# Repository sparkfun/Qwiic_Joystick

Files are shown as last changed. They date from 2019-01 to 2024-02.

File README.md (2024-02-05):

SparkFun Qwiic Joystick
========================================

SparkFun Qwiic Joystick

[*SparkFun Qwiic Joystick (COM-15168)*](https://www.sparkfun.com/products/15168)

Now, you can easily add an HID/controller to your project! The [SparkFun Qwiic Joystick](https://www.sparkfun.com/products/15168) combines the convenience of the Qwiic connection system and an analog joystick that feels reminiscent of the _thumbstick_ from a PlayStation 2 controller.

Thanks to an ATtiny85 on the [Qwiic Joystick](https://www.sparkfun.com/products/15168), all the necessary bits are taken care of and your microcontroller only needs to look for your inputs in the registers of the I<sup>2</sup>C device.

<h3 style="text-decoration: underline;">Factory Default I2C Slave Address: 0x20</h3>

<h3 style="text-decoration: underline;">I2C Registers</h3><br/>

| Address | Contents |
| --- | --- |
| 0x00 | Default I2C Address |
| 0x01-0x02 | Firmware Version |
| 0x03-0x04 | Horizontal Position (MSB First) |
| 0x05-0x06 | Vertical Position (MSB First) |
| 0x07 | Button Position; clears after read. |
| 0x08 | Button Status: Indicates if button was pressed since last read of button state (i.e. last time reg `0x07` was read). |
| 0x09 | Lock Register for I2C Address Change |
| 0x0A | Current I2C Slave Address. Can only be changed once Lock Register is set to 0x13, then it clears the Lock Register. |

In the registers for the joystick position, the MSB contains the first 8 bits of the 10-bit ADC value and the LSB contains the last two bits. As an example, this is how the library converts the two registers back to a 10-bit value.

`uint_16t full10bitvalue = (MSB | LSB)>>6;`

You could potentially only look at the MSB and get an 8-bit (256 position) reading. The firmware was intentionally written this way in the hopes that it would be useful for customers who don't need the full resolution of the joystick position.

Repository Contents
-------------------

* **/Firmware** - Firmware for ATtiny85 and Python Example Code 
* **/Hardware** - Eagle design files (.brd, .sch)

Documentation
--------------
* **[Library](https://github.com/sparkfun/SparkFun_Qwiic_Joystick_Arduino_Library)** - Arduino library for the Qwiic Joystick.
* **[Hookup Guide](https://learn.sparkfun.com/tutorials/qwiic-joystick-hookup-guide)** - Basic hookup guide for the Qwiic Joystick.

Product Versions
----------------
* [COM-15168](https://www.sparkfun.com/products/15168)- Retail packaging of standard description here

Version History
---------------
* [SparkFun Qwiic Joystick COM-15168](https://www.sparkfun.com/products/15168) - Firmware was update so that the board acts like a *normal* I2C slave device, the silk screen was changed to follow retail product guidelines, and the ISP pins were reconfigured for programming on a test bed.
* [SparkX Qwiic Joystiic v1.1 SPX-14656](https://www.sparkfun.com/products/14656) - Version 1.1 is a minor revision which adds a power LED and corrects the wide IC footprint. It's functionally identical to the previous version.
* [SparkX Qwiic Joystiic SPX-14619](https://www.sparkfun.com/products/retired/14619) - Original SparkX Joystiic.

License Information
-------------------

This product is _**open source**_! 

Please review the LICENSE.md file for license information. 

If you have any questions or concerns on licensing, please visit the [SparkFun Forum](https://forum.sparkfun.com/index.php) and post a topic. For more general questions related to our qwiic system, please visit this section of the forum: [SparkFun Forums: QWIIC SYSTEMS](https://forum.sparkfun.com/viewforum.php?f=105)

Distributed as-is; no warranty is given.

- Your friends at SparkFun.

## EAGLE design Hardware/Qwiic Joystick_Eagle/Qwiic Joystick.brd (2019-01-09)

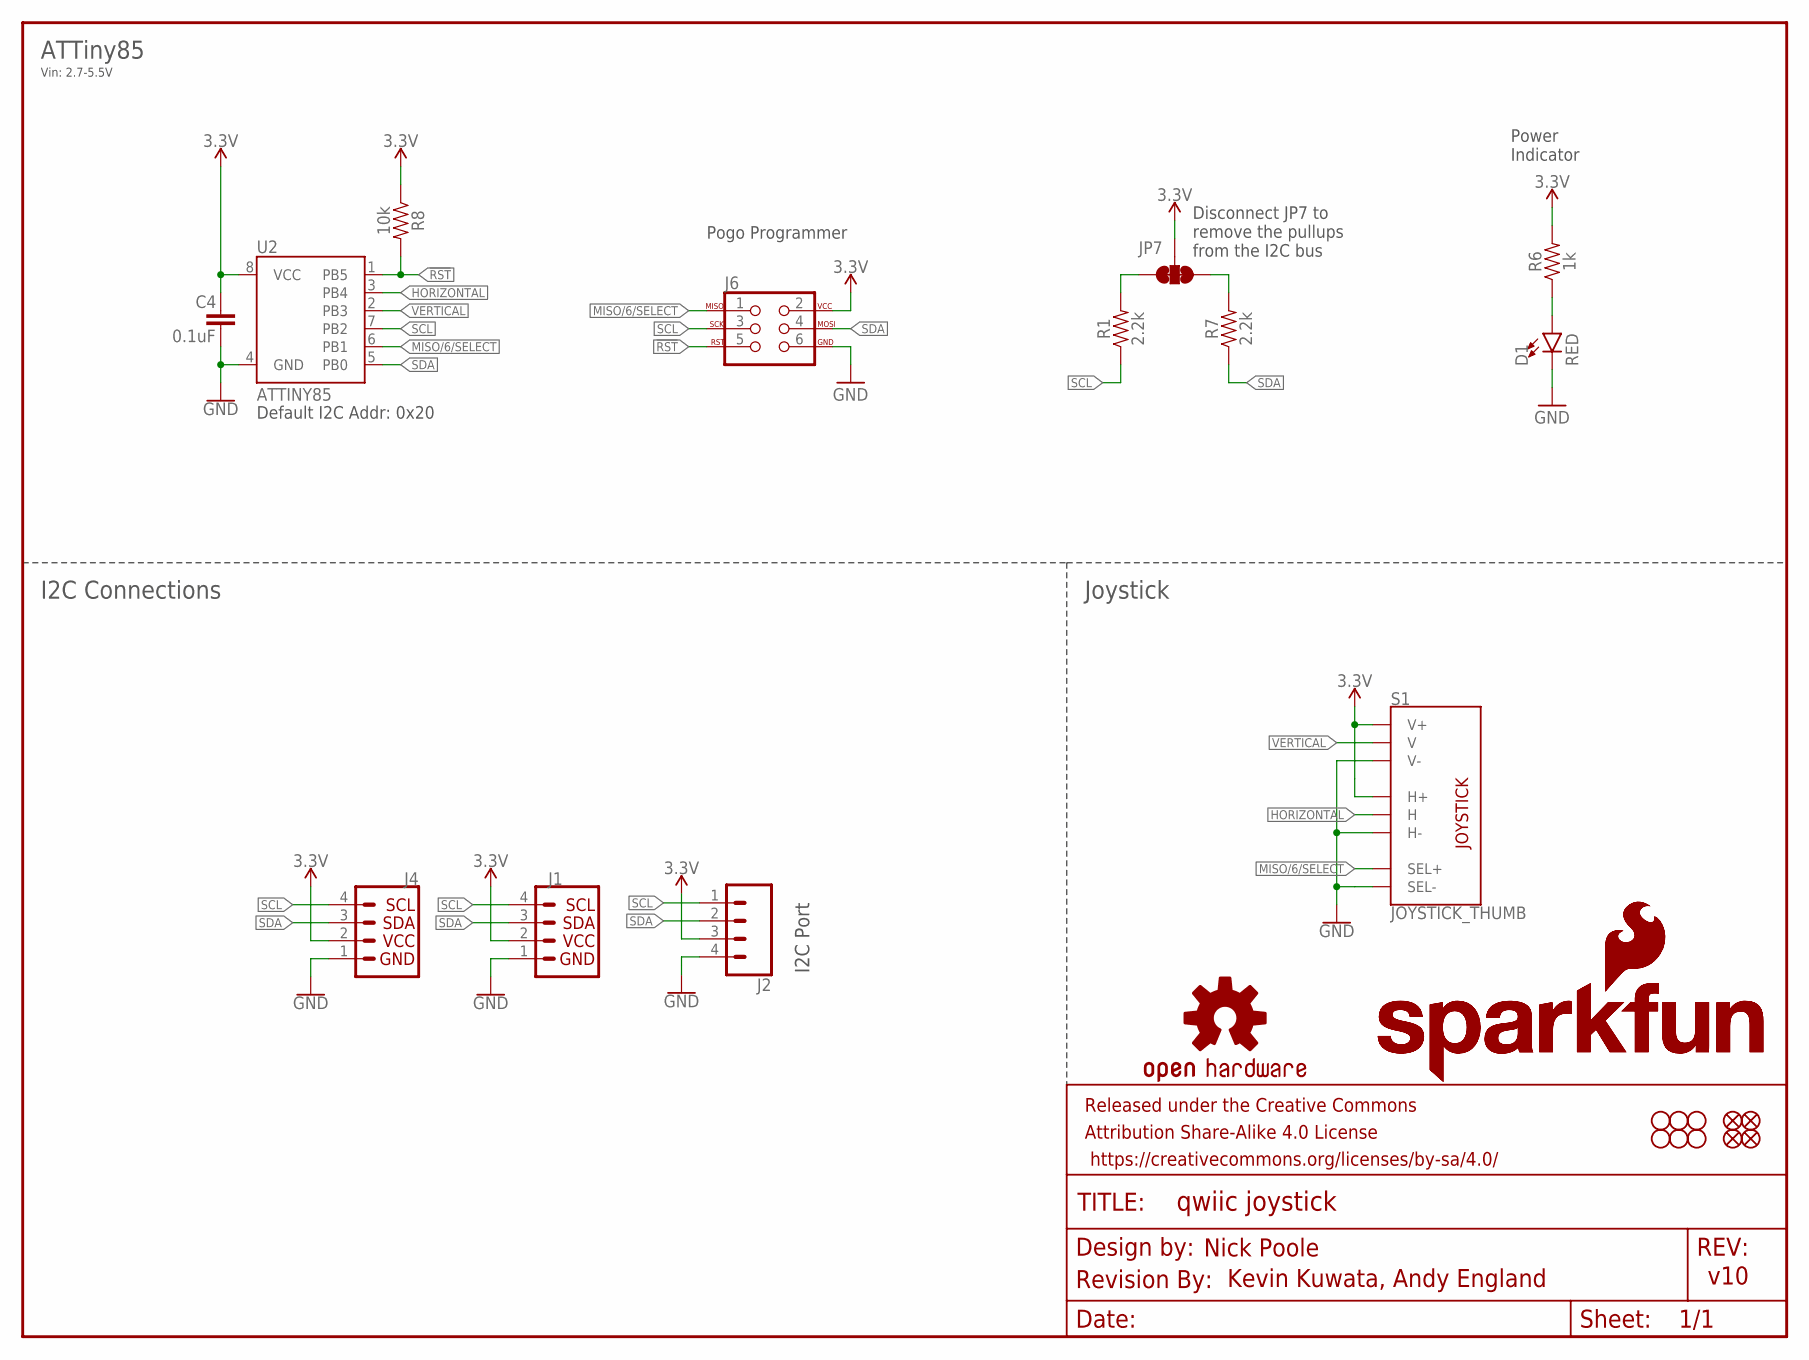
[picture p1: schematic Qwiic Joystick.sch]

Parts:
C4: 0.1uF; 0603
D1: RED; LED-0603
FRAME1: FRAME-LETTER; CREATIVE_COMMONS
H1, H2, H3, H4, H5, H6: STAND-OFF
J1, J4: QWIIC_CONNECTORJS-1MM; 1X04_1MM_RA
J2: CONN_041X04_NO_SILK; 1X04_NO_SILK
J6: AVR_SPI_PROG_3X2TESTPOINTS; 2X3_TEST_POINTS
JP1, JP2, JP3, JP6: FIDUCIALUFIDUCIAL; MICRO-FIDUCIAL
JP7: JUMPER-SMT_3_2-NC_TRACE_NO-SILK; SMT-JUMPER_3_2-NC_TRACE_NO-SILK
LOGO1: OSHW-LOGOMINI; OSHW-LOGO-MINI
LOGO2: REVISION
R1, R7: 2.2k; 0603
R6: 1k; 0603
R8: 10k; 0603
S1: JOYSTICK_THUMB; JOYSTICK
U2: ATTINY85
U$1, U$2: SFE_LOGO_NAME_FLAME.1_INCH; SFE_LOGO_NAME_FLAME_.1

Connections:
3.3V: C4.1, J1.2, J2.3, J4.2, J6.2, JP7.2, R6.2, R8.1, S1.H1 (H+), S1.V1 (V+), U2.8 (VCC)
!RST: J6.5, R8.2, U2.1 (PB5)
GND: C4.2, D1.C, J1.1, J2.4, J4.1, J6.6, S1.B2A (SEL-), S1.H3 (H-), S1.V3 (V-), U2.4 (GND)
HORIZONTAL: S1.H2 (H), U2.3 (PB4)
MISO/6/SELECT: J6.1, S1.B1A (SEL+), U2.6 (PB1)
unnamed: D1.A, R6.1
unnamed: JP7.1, R7.2
unnamed: JP7.3, R1.2
SCL: J1.4, J2.1, J4.4, J6.3, R1.1, U2.7 (PB2)
SDA: J1.3, J2.2, J4.3, J6.4, R7.1, U2.5 (PB0)
VERTICAL: S1.V2 (V), U2.2 (PB3)

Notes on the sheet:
Nick Poole
v10
Power Indicator
Kevin Kuwata, Andy England
I2C Port
Pogo Programmer
Default I2C Addr: 0x20
Disconnect JP7 to remove the pullups from the I2C bus
ATTiny85
Joystick
I2C Connections
Vin: 2.7-5.5V

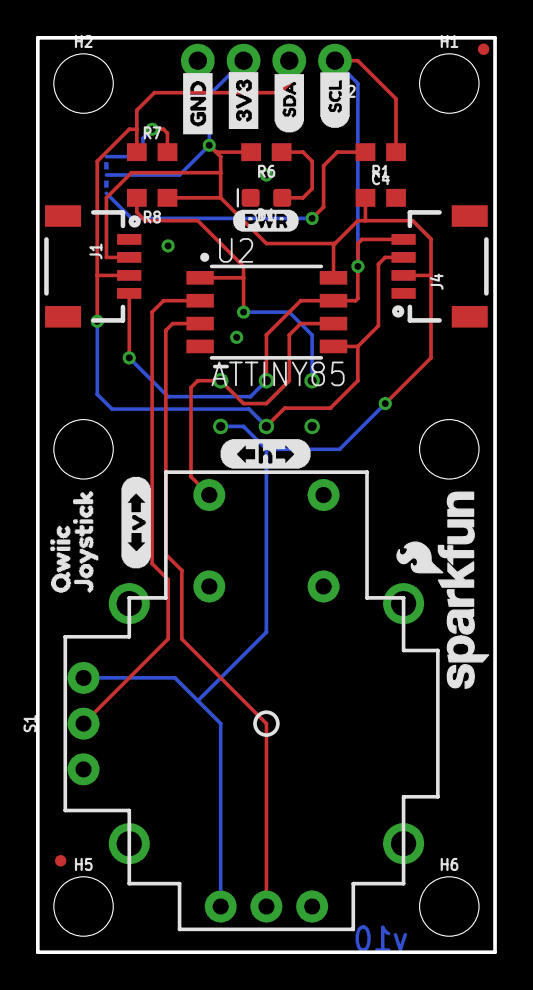
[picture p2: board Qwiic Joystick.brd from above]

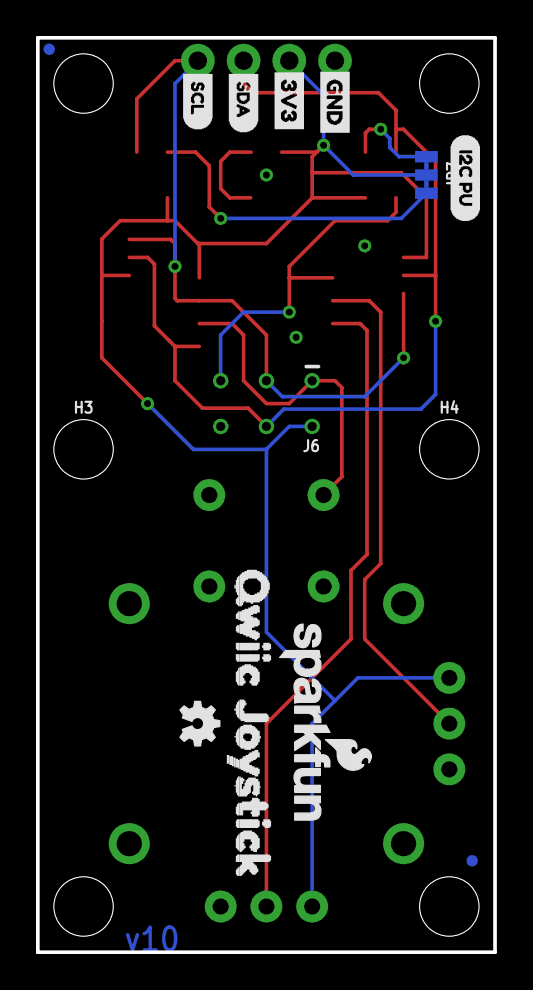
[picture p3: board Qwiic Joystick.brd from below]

Board: 2 copper layers, 25.4 x 50.8 mm, 43 parts (14 on the bottom side), 11 nets.

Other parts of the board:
U$3: QWIIC0
U$4: I2C_PU0
U$5: SDA0
U$6, U$8: GND4
U$7: ##V##1
U$9: SCL1
U$10: JOYSTICK0
U$11: SCL3
U$12: SDA2
U$13: QWIIC_JOYSTICK1
U$14: PWR-()-03
U$15: ##H##0
U$16, U$17: 3V35

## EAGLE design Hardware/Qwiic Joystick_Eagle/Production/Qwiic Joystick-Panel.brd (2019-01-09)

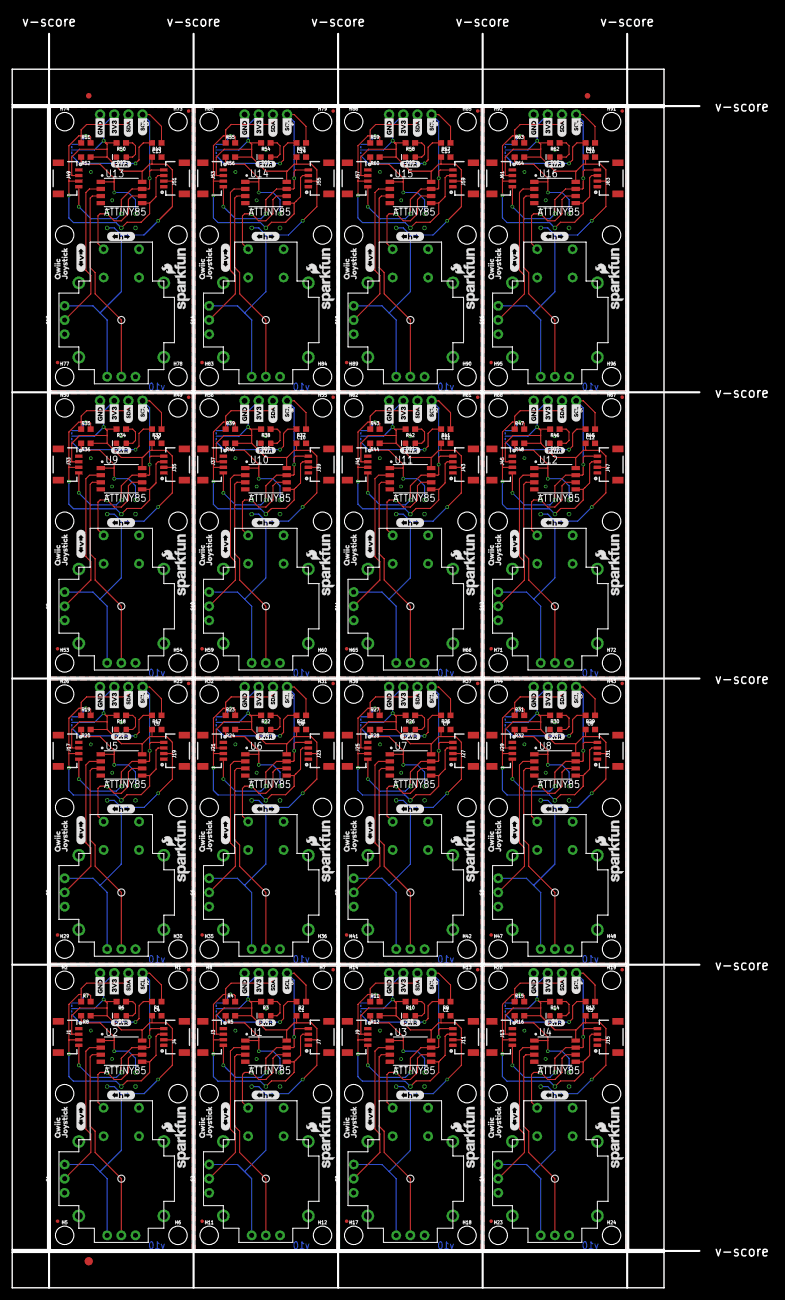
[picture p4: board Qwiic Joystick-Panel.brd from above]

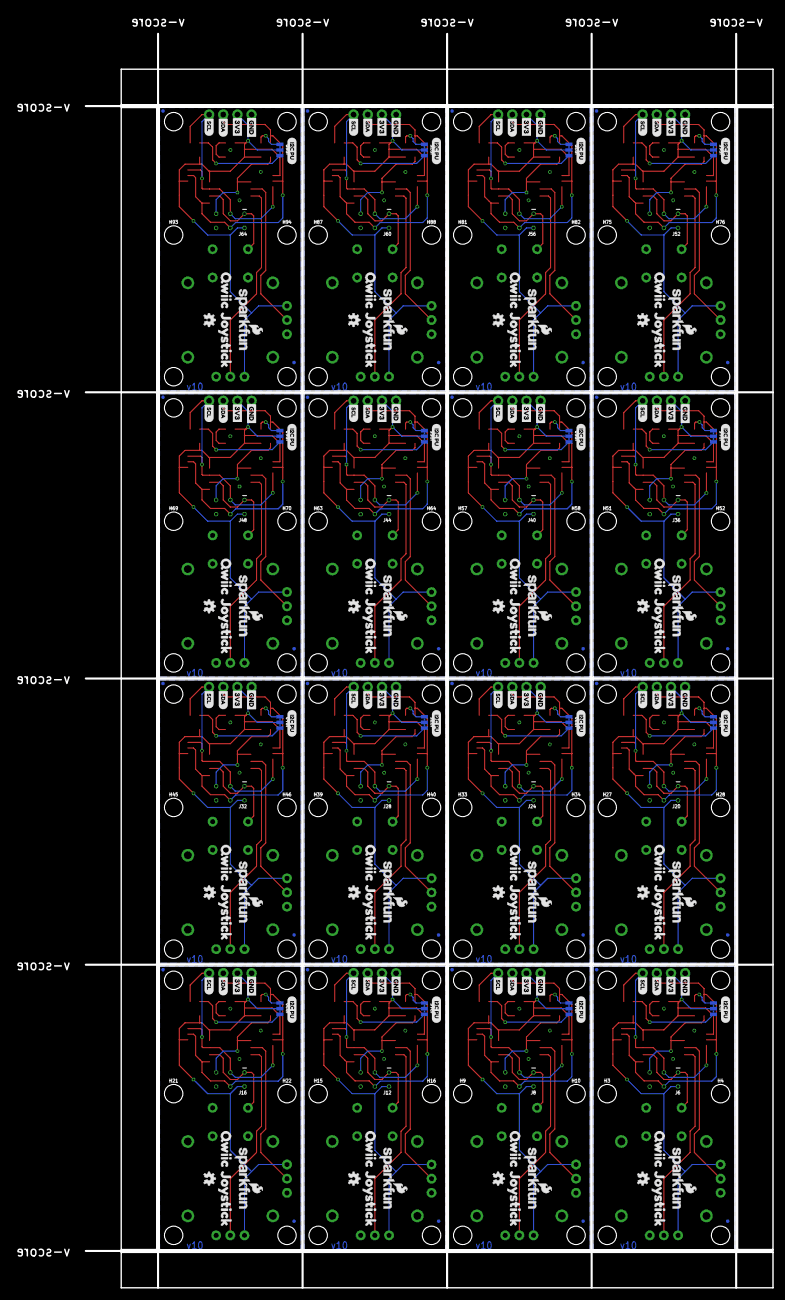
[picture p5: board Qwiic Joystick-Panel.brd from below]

Board: 2 copper layers, 123.2 x 224.8 mm, 675 parts (224 on the bottom side), 176 nets.

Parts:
C1, C2, C3, C4, C5, C6, C7, C8, C9, C10, C11, C12, C13, C14, C15, C16: 0.1uF; 0603
D1, D2, D3, D4, D5, D6, D7, D8, D9, D10, D11, D12, D13, D14, D15, D16: RED; LED-0603
E$1, E$2: FIDUCIAL-1X2
E$3: FIDUCIAL-1.5X3
H1, H2, H3, H4, H5, H6, H7, H8, H9, H10, H11, H12, H13, H14, H15, H16, H17, H18, H19, H20, H21, H22, H23, H24, H25, H26, H27, H28, H29, H30, H31, H32, H33, H34, H35, H36, H37, H38, H39, H40, H41, H42, H43, H44, H45, H46, H47, H48, H49, H50, H51, H52, H53, H54, H55, H56, H57, H58, H59, H60, H61, H62, H63, H64, H65, H66, H67, H68, H69, H70, H71, H72, H73, H74, H75, H76, H77, H78, H79, H80, H81, H82, H83, H84, H85, H86, H87, H88, H89, H90, H91, H92, H93, H94, H95, H96: STAND-OFF
J1, J3, J4, J7, J9, J11, J13, J15, J17, J19, J21, J23, J25, J27, J29, J31, J33, J35, J37, J39, J41, J43, J45, J47, J49, J51, J53, J55, J57, J59, J61, J63: 1X04_1MM_RA
J2, J5, J10, J14, J18, J22, J26, J30, J34, J38, J42, J46, J50, J54, J58, J62: 1X04_NO_SILK
J6, J8, J12, J16, J20, J24, J28, J32, J36, J40, J44, J48, J52, J56, J60, J64: AVR_SPI_PROG_3X2TESTPOINTS; 2X3_TEST_POINTS
JP1, JP2, JP3, JP4, JP5, JP6, JP8, JP9, JP11, JP12, JP13, JP14, JP16, JP17, JP18, JP19, JP21, JP22, JP23, JP24, JP26, JP27, JP28, JP29, JP31, JP32, JP33, JP34, JP36, JP37, JP38, JP39, JP41, JP42, JP43, JP44, JP46, JP47, JP48, JP49, JP51, JP52, JP53, JP54, JP56, JP57, JP58, JP59, JP61, JP62, JP63, JP64, JP66, JP67, JP68, JP69, JP71, JP72, JP73, JP74, JP76, JP77, JP78, JP79: FIDUCIALUFIDUCIAL; MICRO-FIDUCIAL
JP7, JP10, JP15, JP20, JP25, JP30, JP35, JP40, JP45, JP50, JP55, JP60, JP65, JP70, JP75, JP80: JUMPER-SMT_3_2-NC_TRACE_NO-SILK; SMT-JUMPER_3_2-NC_TRACE_NO-SILK
LOGO1, LOGO3, LOGO5, LOGO7, LOGO9, LOGO11, LOGO13, LOGO15, LOGO17, LOGO19, LOGO21, LOGO23, LOGO25, LOGO27, LOGO29, LOGO31: OSHW-LOGOMINI; OSHW-LOGO-MINI
LOGO2, LOGO4, LOGO6, LOGO8, LOGO10, LOGO12, LOGO14, LOGO16, LOGO18, LOGO20, LOGO22, LOGO24, LOGO26, LOGO28, LOGO30, LOGO32: REVISION
R1, R2, R4, R7, R9, R11, R13, R15, R17, R19, R21, R23, R25, R27, R29, R31, R33, R35, R37, R39, R41, R43, R45, R47, R49, R51, R53, R55, R57, R59, R61, R63: 2.2k; 0603
R3, R6, R10, R14, R18, R22, R26, R30, R34, R38, R42, R46, R50, R54, R58, R62: 1k; 0603
R5, R8, R12, R16, R20, R24, R28, R32, R36, R40, R44, R48, R52, R56, R60, R64: 10k; 0603
S1, S2, S3, S4, S5, S6, S7, S8, S9, S10, S11, S12, S13, S14, S15, S16: JOYSTICK_THUMB; JOYSTICK
U1, U2, U3, U4, U5, U6, U7, U8, U9, U10, U11, U12, U13, U14, U15, U16: ATTINY85
U$1, U$2, U$18, U$19, U$35, U$36, U$52, U$53, U$69, U$70, U$86, U$87, U$103, U$104, U$120, U$121, U$137, U$138, U$154, U$155, U$171, U$172, U$188, U$189, U$205, U$206, U$222, U$223, U$239, U$240, U$256, U$257: SFE_LOGO_NAME_FLAME.1_INCH; SFE_LOGO_NAME_FLAME_.1
U$3, U$33, U$50, U$67, U$84, U$101, U$118, U$135, U$152, U$169, U$186, U$203, U$220, U$237, U$254, U$271: QWIIC0
U$4, U$31, U$48, U$65, U$82, U$99, U$116, U$133, U$150, U$167, U$184, U$201, U$218, U$235, U$252, U$269: I2C_PU0
U$5, U$23, U$40, U$57, U$74, U$91, U$108, U$125, U$142, U$159, U$176, U$193, U$210, U$227, U$244, U$261: SDA0
U$6, U$8, U$27, U$28, U$44, U$45, U$61, U$62, U$78, U$79, U$95, U$96, U$112, U$113, U$129, U$130, U$146, U$147, U$163, U$164, U$180, U$181, U$197, U$198, U$214, U$215, U$231, U$232, U$248, U$249, U$265, U$266: GND4
U$7, U$21, U$38, U$55, U$72, U$89, U$106, U$123, U$140, U$157, U$174, U$191, U$208, U$225, U$242, U$259: ##V##1
U$9, U$24, U$41, U$58, U$75, U$92, U$109, U$126, U$143, U$160, U$177, U$194, U$211, U$228, U$245, U$262: SCL1
U$10, U$34, U$51, U$68, U$85, U$102, U$119, U$136, U$153, U$170, U$187, U$204, U$221, U$238, U$255, U$272: JOYSTICK0
U$11, U$25, U$42, U$59, U$76, U$93, U$110, U$127, U$144, U$161, U$178, U$195, U$212, U$229, U$246, U$263: SCL3
U$12, U$26, U$43, U$60, U$77, U$94, U$111, U$128, U$145, U$162, U$179, U$196, U$213, U$230, U$247, U$264: SDA2
U$13, U$32, U$49, U$66, U$83, U$100, U$117, U$134, U$151, U$168, U$185, U$202, U$219, U$236, U$253, U$270: QWIIC_JOYSTICK1
U$14, U$20, U$37, U$54, U$71, U$88, U$105, U$122, U$139, U$156, U$173, U$190, U$207, U$224, U$241, U$258: PWR-()-03
U$15, U$22, U$39, U$56, U$73, U$90, U$107, U$124, U$141, U$158, U$175, U$192, U$209, U$226, U$243, U$260: ##H##0
U$16, U$17, U$29, U$30, U$46, U$47, U$63, U$64, U$80, U$81, U$97, U$98, U$114, U$115, U$131, U$132, U$148, U$149, U$165, U$166, U$182, U$183, U$199, U$200, U$216, U$217, U$233, U$234, U$250, U$251, U$267, U$268: 3V35

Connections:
3.3V: C4.1, J1.2, J2.3, J4.2, J6.2, JP7.2, R6.2, R8.1, S1.H1, S1.V1, U2.8
3.3V1: C1.1, J3.2, J5.3, J7.2, J8.2, JP10.2, R3.2, R5.1, S2.H1, S2.V1, U1.8
3.3V2: C2.1, J9.2, J10.3, J11.2, J12.2, JP15.2, R10.2, R12.1, S3.H1, S3.V1, U3.8
3.3V3: C3.1, J13.2, J14.3, J15.2, J16.2, JP20.2, R14.2, R16.1, S4.H1, S4.V1, U4.8
3.3V4: C5.1, J17.2, J18.3, J19.2, J20.2, JP25.2, R18.2, R20.1, S5.H1, S5.V1, U5.8
3.3V5: C6.1, J21.2, J22.3, J23.2, J24.2, JP30.2, R22.2, R24.1, S6.H1, S6.V1, U6.8
3.3V6: C7.1, J25.2, J26.3, J27.2, J28.2, JP35.2, R26.2, R28.1, S7.H1, S7.V1, U7.8
3.3V7: C8.1, J29.2, J30.3, J31.2, J32.2, JP40.2, R30.2, R32.1, S8.H1, S8.V1, U8.8
3.3V8: C9.1, J33.2, J34.3, J35.2, J36.2, JP45.2, R34.2, R36.1, S9.H1, S9.V1, U9.8
3.3V9: C10.1, J37.2, J38.3, J39.2, J40.2, JP50.2, R38.2, R40.1, S10.H1, S10.V1, U10.8
3.3V10: C11.1, J41.2, J42.3, J43.2, J44.2, JP55.2, R42.2, R44.1, S11.H1, S11.V1, U11.8
3.3V11: C12.1, J45.2, J46.3, J47.2, J48.2, JP60.2, R46.2, R48.1, S12.H1, S12.V1, U12.8
3.3V12: C13.1, J49.2, J50.3, J51.2, J52.2, JP65.2, R50.2, R52.1, S13.H1, S13.V1, U13.8
3.3V13: C14.1, J53.2, J54.3, J55.2, J56.2, JP70.2, R54.2, R56.1, S14.H1, S14.V1, U14.8
3.3V14: C15.1, J57.2, J58.3, J59.2, J60.2, JP75.2, R58.2, R60.1, S15.H1, S15.V1, U15.8
3.3V15: C16.1, J61.2, J62.3, J63.2, J64.2, JP80.2, R62.2, R64.1, S16.H1, S16.V1, U16.8
!RST: J6.5, R8.2, U2.1
!RST1: J8.5, R5.2, U1.1
!RST2: J12.5, R12.2, U3.1
!RST3: J16.5, R16.2, U4.1
!RST4: J20.5, R20.2, U5.1
!RST5: J24.5, R24.2, U6.1
!RST6: J28.5, R28.2, U7.1
!RST7: J32.5, R32.2, U8.1
!RST8: J36.5, R36.2, U9.1
!RST9: J40.5, R40.2, U10.1
!RST10: J44.5, R44.2, U11.1
!RST11: J48.5, R48.2, U12.1
!RST12: J52.5, R52.2, U13.1
!RST13: J56.5, R56.2, U14.1
!RST14: J60.5, R60.2, U15.1
!RST15: J64.5, R64.2, U16.1
GND: C4.2, D1.C, J1.1, J2.4, J4.1, J6.6, S1.B2A, S1.H3, S1.V3, U2.4
GND1: C1.2, D2.C, J3.1, J5.4, J7.1, J8.6, S2.B2A, S2.H3, S2.V3, U1.4
GND2: C2.2, D3.C, J9.1, J10.4, J11.1, J12.6, S3.B2A, S3.H3, S3.V3, U3.4
GND3: C3.2, D4.C, J13.1, J14.4, J15.1, J16.6, S4.B2A, S4.H3, S4.V3, U4.4
GND4: C5.2, D5.C, J17.1, J18.4, J19.1, J20.6, S5.B2A, S5.H3, S5.V3, U5.4
GND5: C6.2, D6.C, J21.1, J22.4, J23.1, J24.6, S6.B2A, S6.H3, S6.V3, U6.4
GND6: C7.2, D7.C, J25.1, J26.4, J27.1, J28.6, S7.B2A, S7.H3, S7.V3, U7.4
GND7: C8.2, D8.C, J29.1, J30.4, J31.1, J32.6, S8.B2A, S8.H3, S8.V3, U8.4
GND8: C9.2, D9.C, J33.1, J34.4, J35.1, J36.6, S9.B2A, S9.H3, S9.V3, U9.4
GND9: C10.2, D10.C, J37.1, J38.4, J39.1, J40.6, S10.B2A, S10.H3, S10.V3, U10.4
GND10: C11.2, D11.C, J41.1, J42.4, J43.1, J44.6, S11.B2A, S11.H3, S11.V3, U11.4
GND11: C12.2, D12.C, J45.1, J46.4, J47.1, J48.6, S12.B2A, S12.H3, S12.V3, U12.4
GND12: C13.2, D13.C, J49.1, J50.4, J51.1, J52.6, S13.B2A, S13.H3, S13.V3, U13.4
GND13: C14.2, D14.C, J53.1, J54.4, J55.1, J56.6, S14.B2A, S14.H3, S14.V3, U14.4
GND14: C15.2, D15.C, J57.1, J58.4, J59.1, J60.6, S15.B2A, S15.H3, S15.V3, U15.4
GND15: C16.2, D16.C, J61.1, J62.4, J63.1, J64.6, S16.B2A, S16.H3, S16.V3, U16.4
HORIZONTAL: S1.H2, U2.3
HORIZONTAL1: S2.H2, U1.3
HORIZONTAL2: S3.H2, U3.3
HORIZONTAL3: S4.H2, U4.3
HORIZONTAL4: S5.H2, U5.3
HORIZONTAL5: S6.H2, U6.3
HORIZONTAL6: S7.H2, U7.3
HORIZONTAL7: S8.H2, U8.3
HORIZONTAL8: S9.H2, U9.3
HORIZONTAL9: S10.H2, U10.3
HORIZONTAL10: S11.H2, U11.3
HORIZONTAL11: S12.H2, U12.3
HORIZONTAL12: S13.H2, U13.3
HORIZONTAL13: S14.H2, U14.3
HORIZONTAL14: S15.H2, U15.3
HORIZONTAL15: S16.H2, U16.3
MISO/6/SELECT: J6.1, S1.B1A, U2.6
MISO/6/SELECT1: J8.1, S2.B1A, U1.6
MISO/6/SELECT2: J12.1, S3.B1A, U3.6
MISO/6/SELECT3: J16.1, S4.B1A, U4.6
MISO/6/SELECT4: J20.1, S5.B1A, U5.6
MISO/6/SELECT5: J24.1, S6.B1A, U6.6
MISO/6/SELECT6: J28.1, S7.B1A, U7.6
MISO/6/SELECT7: J32.1, S8.B1A, U8.6
MISO/6/SELECT8: J36.1, S9.B1A, U9.6
MISO/6/SELECT9: J40.1, S10.B1A, U10.6
MISO/6/SELECT10: J44.1, S11.B1A, U11.6
MISO/6/SELECT11: J48.1, S12.B1A, U12.6
MISO/6/SELECT12: J52.1, S13.B1A, U13.6
MISO/6/SELECT13: J56.1, S14.B1A, U14.6
MISO/6/SELECT14: J60.1, S15.B1A, U15.6
MISO/6/SELECT15: J64.1, S16.B1A, U16.6
unnamed: D1.A, R6.1
unnamed: JP7.1, R7.2
unnamed: JP7.3, R1.2
unnamed: D2.A, R3.1
unnamed: JP10.1, R4.2
unnamed: JP10.3, R2.2
unnamed: D3.A, R10.1
unnamed: JP15.1, R11.2
unnamed: JP15.3, R9.2
unnamed: D4.A, R14.1
unnamed: JP20.1, R15.2
unnamed: JP20.3, R13.2
unnamed: D5.A, R18.1
unnamed: JP25.1, R19.2
unnamed: JP25.3, R17.2
unnamed: D6.A, R22.1
unnamed: JP30.1, R23.2
unnamed: JP30.3, R21.2
unnamed: D7.A, R26.1
unnamed: JP35.1, R27.2
unnamed: JP35.3, R25.2
unnamed: D8.A, R30.1
unnamed: JP40.1, R31.2
unnamed: JP40.3, R29.2
unnamed: D9.A, R34.1
unnamed: JP45.1, R35.2
unnamed: JP45.3, R33.2
unnamed: D10.A, R38.1
unnamed: JP50.1, R39.2
unnamed: JP50.3, R37.2
unnamed: D11.A, R42.1
unnamed: JP55.1, R43.2
unnamed: JP55.3, R41.2
unnamed: D12.A, R46.1
unnamed: JP60.1, R47.2
unnamed: JP60.3, R45.2
unnamed: D13.A, R50.1
unnamed: JP65.1, R51.2
unnamed: JP65.3, R49.2
unnamed: D14.A, R54.1
unnamed: JP70.1, R55.2
unnamed: JP70.3, R53.2
unnamed: D15.A, R58.1
unnamed: JP75.1, R59.2
unnamed: JP75.3, R57.2
unnamed: D16.A, R62.1
unnamed: JP80.1, R63.2
unnamed: JP80.3, R61.2
SCL: J1.4, J2.1, J4.4, J6.3, R1.1, U2.7
SCL1: J3.4, J5.1, J7.4, J8.3, R2.1, U1.7
SCL2: J9.4, J10.1, J11.4, J12.3, R9.1, U3.7
SCL3: J13.4, J14.1, J15.4, J16.3, R13.1, U4.7
SCL4: J17.4, J18.1, J19.4, J20.3, R17.1, U5.7
SCL5: J21.4, J22.1, J23.4, J24.3, R21.1, U6.7
SCL6: J25.4, J26.1, J27.4, J28.3, R25.1, U7.7
SCL7: J29.4, J30.1, J31.4, J32.3, R29.1, U8.7
SCL8: J33.4, J34.1, J35.4, J36.3, R33.1, U9.7
SCL9: J37.4, J38.1, J39.4, J40.3, R37.1, U10.7
SCL10: J41.4, J42.1, J43.4, J44.3, R41.1, U11.7
SCL11: J45.4, J46.1, J47.4, J48.3, R45.1, U12.7
SCL12: J49.4, J50.1, J51.4, J52.3, R49.1, U13.7
SCL13: J53.4, J54.1, J55.4, J56.3, R53.1, U14.7
SCL14: J57.4, J58.1, J59.4, J60.3, R57.1, U15.7
SCL15: J61.4, J62.1, J63.4, J64.3, R61.1, U16.7
SDA: J1.3, J2.2, J4.3, J6.4, R7.1, U2.5
SDA1: J3.3, J5.2, J7.3, J8.4, R4.1, U1.5
SDA2: J9.3, J10.2, J11.3, J12.4, R11.1, U3.5
SDA3: J13.3, J14.2, J15.3, J16.4, R15.1, U4.5
SDA4: J17.3, J18.2, J19.3, J20.4, R19.1, U5.5
SDA5: J21.3, J22.2, J23.3, J24.4, R23.1, U6.5
SDA6: J25.3, J26.2, J27.3, J28.4, R27.1, U7.5
SDA7: J29.3, J30.2, J31.3, J32.4, R31.1, U8.5
SDA8: J33.3, J34.2, J35.3, J36.4, R35.1, U9.5
SDA9: J37.3, J38.2, J39.3, J40.4, R39.1, U10.5
SDA10: J41.3, J42.2, J43.3, J44.4, R43.1, U11.5
SDA11: J45.3, J46.2, J47.3, J48.4, R47.1, U12.5
SDA12: J49.3, J50.2, J51.3, J52.4, R51.1, U13.5
SDA13: J53.3, J54.2, J55.3, J56.4, R55.1, U14.5
SDA14: J57.3, J58.2, J59.3, J60.4, R59.1, U15.5
SDA15: J61.3, J62.2, J63.3, J64.4, R63.1, U16.5
VERTICAL: S1.V2, U2.2
VERTICAL1: S2.V2, U1.2
VERTICAL2: S3.V2, U3.2
VERTICAL3: S4.V2, U4.2
VERTICAL4: S5.V2, U5.2
VERTICAL5: S6.V2, U6.2
VERTICAL6: S7.V2, U7.2
VERTICAL7: S8.V2, U8.2
VERTICAL8: S9.V2, U9.2
VERTICAL9: S10.V2, U10.2
VERTICAL10: S11.V2, U11.2
VERTICAL11: S12.V2, U12.2
VERTICAL12: S13.V2, U13.2
VERTICAL13: S14.V2, U14.2
VERTICAL14: S15.V2, U15.2
VERTICAL15: S16.V2, U16.2

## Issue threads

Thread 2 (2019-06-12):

Button Status Register 0x08 is always 1

fourstix, 2019-06-12:
Reading the button status through the Arduino library checkButton function or even directly through i2c calls to read register 0x08 always returns 1.  The register never seems to clear after being explicitly set to 0x00 through a write call in the library.  I traced the error through the Arduino library and it seems to be an issue with the firmware.

fourstix, 2019-06-12:
I am using a Qwiic Joystick with a firmware version of v2.4.

santaimpersonator, 2019-06-18:
You are correct, that is a firmware issue. I must have accidentally undone or overwrote that value in the protection map for the [Button_Status](https://github.com/sparkfun/Qwiic_Joystick/blob/master/Firmware/ATtiny85%20Firmware/Qwiic_Joystick_v24/Qwiic_Joystick_v24.ino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). There is one other thing I would like to double-check before updating the firmware again.

I'll have the tech support team reach out to you in the forum. Thanks for reaching out.

santaimpersonator, 2019-06-19:
Firmware updated. Closing issue.

Closed 2019-06-19.

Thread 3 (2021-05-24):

Button Status Register 0x08 always has 1

Oleh-Kravchenko, 2021-05-24:
Hello!
Probably is a duplicate of https://github.com/sparkfun/Qwiic_Joystick/issues/2,
but still reproducible with firmware version 2.6:
```
$ i2cget -y 1 0x20 1 w
0x0602
```
Button status register:
```
$ i2cget -y 1 0x20 8 b
0x01
```

wohali, 2024-02-02:
I think this is a documentation issue.

Check the following:

```bash
$ i2cget -y 2 0x20 0x08
0x01
$ i2cset -y 2 0x20 0x08 0
$ i2cget -y 2 0x20 0x08
0x00
$ i2cget -y 2 0x20 0x08
0x00
$ # Push button now
$ i2cget -y 2 0x20 0x08
0x01
$ # Clear status
$ i2cset -y 2 0x20 0x08 0
$ i2cget -y 2 0x20 0x08
0x00
```

So just clear the status yourself once you've processed the event.

santaimpersonator, 2024-02-05:
I think this is a misinterpretation of [line 23 in the `README.md`](https://github.com/sparkfun/Qwiic_Joystick/blob/master/README.md?plain=1#L23):

> 0x08 | Button Status: Indicates if button was pressed since last read of button state. Clears after read.

It seems you are misinterpreting the action of reading the register, with its use in our Arduino library:

- If you check the [Arduino library](https://github.com/sparkfun/SparkFun_Qwiic_Joystick_Arduino_Library/blob/master/src/SparkFun_Qwiic_Joystick_Arduino_Library.cpp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):

  ```
  byte JOYSTICK::checkButton()
  {
    byte status = readRegister(JOYSTICK_STATUS);

    writeRegister(JOYSTICK_STATUS, 0x00); //We've read this status bit, now clear it

    return(status);
  }
  ```
- or reference our [hookup guide](https://learn.sparkfun.com/tutorials/qwiic-joystick-hookup-guide#arduino-library):
  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

they both indicate that the register gets cleared by the Arduino library and not the firmware. We intentionally did this to give users more control of how the register is used (i.e. you clear the register once you are done reading from it).

The firmware update in v26 for #2, was to enable that register to be cleared. Previously, the register was protected and could only be read.

As suggested by @wohali, I'll reword that section of the `README.md` to be more clear.

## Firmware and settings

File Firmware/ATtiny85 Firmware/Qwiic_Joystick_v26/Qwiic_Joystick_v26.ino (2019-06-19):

/*
  An I2C based Thumb Joystick
  By: Nathan Seidle
  Modified by: Wes Furuya
  SparkFun Electronics
  Date: February 5, 2019
  License: This code is public domain but you buy me a beer if you use this and we meet someday (Beerware license).
  Qwiic Joystick is an I2C based thumb joystick that reports the joystick position and if the button is pressed.
  Feel like supporting our work? Buy a board from SparkFun!
  https://www.sparkfun.com/products/15168
  To install support for ATtiny84 in Arduino IDE: https://github.com/SpenceKonde/ATTinyCore/blob/master/Installation.md
  This core is installed from the Board Manager menu
  This core has built in support for I2C S/M and serial
  If you have Dave Mellis' ATtiny installed you may need to remove it from \Users\xx\AppData\Local\Arduino15\Packages
  To support 400kHz I2C communication reliably ATtiny84 needs to run at 8MHz. This requires user to
  click on 'Burn Bootloader' before code is loaded.
*/

#include <Wire.h>
#include <EEPROM.h>
#include "nvm.h"

#if defined(__AVR_ATtiny85__)
#include "PinChangeInterrupt.h" //Nico Hood's library: https://github.com/NicoHood/PinChangeInterrupt/
//Used for pin change interrupts on ATtinys (joystick button causes interrupt)
//Note: To make this code work with Nico's library you have to comment out https://github.com/NicoHood/PinChangeInterrupt/blob/master/src/PinChangeInterruptSettings.h#L228
#endif

#include <avr/sleep.h> //Needed for sleep_mode
#include <avr/power.h> //Needed for powering down perihperals such as the ADC/TWI and Timers

#if defined(__AVR_ATmega328P__)
//Hardware connections while developing with an Uno
const byte Button_Pin = 2;
const byte Vertical_Pin = A1;
const byte Horizontal_Pin = A0;

#elif defined(__AVR_ATtiny85__)
////For Debug Only
//#include <SoftwareSerial.h>
//#define TX    3   //P3, Pin 2
//#define RX    4   //P4, Pin 3
//SoftwareSerial TinySerial(RX, TX);

//Hardware connections for the final design
const byte Button_Pin = 1;
const byte Vertical_Pin = 3;
const byte Horizontal_Pin = 2;
#endif

//Global variables
//-=-=-=-=-=-=-=-=-=-=-=-=-=-=-=-=-=-=-=-=-=-=-=-=-=-=-=-=-=-=-=-=-=-=-=-=-=-=-=-=-=-=-=-=-=-
//Variables used in the I2C interrupt so we use volatile

//This is the pseudo register map of the product. If user asks for 0x02 then get the 3rd
//byte inside the register map.
//5602/118 on ATtiny84 prior to conversion
//Approximately 4276/156 on ATtiny84 after conversion
struct memoryMap {
  byte id;              // Reg: 0x00 - Default I2C Address
  byte firmwareMajor;   // Reg: 0x01 - Firmware Number
  byte firmwareMinor;   // Reg: 0x02 - Firmware Number
  byte X_MSB;           // Reg: 0x03 - Current Joystick Horizontal Position (MSB)
  byte X_LSB;           // Reg: 0x04 - Current Joystick Horizontal Position (LSB)
  byte Y_MSB;           // Reg: 0x05 - Current Joystick Vertical Position (MSB)
  byte Y_LSB;           // Reg: 0x06 - Current Joystick Vertical Position (LSB)
  byte Button_State;    // Reg: 0x07 - Current Button State (clears Reg 0x08)
  byte Button_Status;   // Reg: 0x08 - Indicator for if button was pressed since last
                        //             read of button state (Reg 0x07). Clears after read.
  byte i2cLock;         // Reg: 0x09 - Must be changed to 0x13 before I2C address can be changed.
  byte i2cAddress;      // Reg: 0x0A - Set I2C New Address (re-writable). Clears i2cLock.
};

//These are the default values for all settings
volatile memoryMap registerMap = {
  .id = I2C_ADDRESS_DEFAULT, //Default I2C Address (0x20)
  .firmwareMajor = 0x02, //Firmware version. Helpful for tech support.
  .firmwareMinor = 0x06,
  .X_MSB = 0,
  .X_LSB = 0,
  .Y_MSB = 0,
  .Y_LSB = 0,
  .Button_State = 0x00,
  .Button_Status = 0x00,
  .i2cLock = 0x00,
  .i2cAddress = I2C_ADDRESS_DEFAULT,
};

//This defines which of the registers are read-only (0) vs read-write (1)
memoryMap protectionMap = {
  .id = 0x00,
  .firmwareMajor = 0x00,
  .firmwareMinor = 0x00,
  .X_MSB = 0x00,
  .X_LSB = 0x00,
  .Y_MSB = 0x00,
  .Y_LSB = 0x00,
  .Button_State = 0x00,
  .Button_Status = 0x01,
  .i2cLock = 0xFF,
  .i2cAddress = 0xFF,
};

//Cast 32bit address of the object registerMap with uint8_t so we can increment the pointer
uint8_t *registerPointer = (uint8_t *)&registerMap;
uint8_t *protectionPointer = (uint8_t *)&protectionMap;

volatile byte registerNumber; //Gets set when user writes an address. We then serve the spot the user requested.

//-=-=-=-=-=-=-=-=-=-=-=-=-=-=-=-=-=-=-=-=-=-=-=-=-=-=-=-=-=-=-=-=-=-=-=-=-=-=-=-=-=-=-=-=-=-


void setup(void)
{
  //Pin Definitions
  pinMode(Button_Pin, INPUT_PULLUP);
  pinMode(Vertical_Pin, INPUT); //No pull-up. External 10k
  pinMode(Horizontal_Pin, INPUT); //No pull-up. External 10k

  turnOffExtraBits(); //Turn off all unused peripherals
  readSystemSettings(); //Load all system settings from EEPROM
  setupInterrupts(); //Enable pin change interrupts for I2C and button
  startI2C(); //Determine the I2C address we should be using and begin listening on I2C bus

#if defined(__AVR_ATmega328P__)
  Serial.begin(9600);
  Serial.println("Qwiic Joystick");
  Serial.print("Address: 0x");
  Serial.print(registerMap.i2cAddress, HEX);
  Serial.println();
//// For Debug
//#else defined(__AVR_ATtiny85__)
//  TinySerial.begin(9600);
//  TinySerial.println("Qwiic Joystick");
//  TinySerial.print("Address: 0x");
//  TinySerial.print(registerMap.i2cAddress, HEX);
//  TinySerial.println();
#endif
}

void loop(void)
{

// Debug and Testing
#if defined(__AVR_ATmega328P__)

  updateJoystick();
  
  uint16_t X_Pos =  ((registerMap.X_MSB<<8) | registerMap.X_LSB)>>6;
  uint16_t Y_Pos =  ((registerMap.Y_MSB<<8) | registerMap.Y_LSB)>>6;

  Serial.print("X: ");
  Serial.print(X_Pos);

  Serial.print(" Y: ");
  Serial.print(Y_Pos);

  Serial.print(" Reg: ");
  Serial.print(registerMap.i2cAddress);
  
  Serial.print(" ID: ");
  Serial.print(registerMap.i2cLock);

  if (registerMap.Button_Status == 1)
    Serial.print(" Click");


//  Serial.print(registerMap.id, HEX);
//  Serial.print(" ");
//  Serial.print(registerMap.firmwareMajor, HEX);
//  Serial.print(".");
//  Serial.print(registerMap.firmwareMinor, HEX);
//  Serial.print(" ");
//  Serial.print(registerMap.X_MSB);
//  Serial.print(registerMap.X_LSB, HEX);
//  Serial.print(" ");
//  Serial.print(registerMap.Y_MSB);
//  Serial.print(registerMap.Y_LSB, HEX);
//  Serial.print(" ");
//  Serial.print(registerMap.Button_State, HEX);
//  Serial.print(" ");
//  Serial.print(registerMap.Button_Status, HEX);
//  Serial.print(" ");
//  Serial.print(registerMap.i2cLock, HEX);
//  Serial.print(" ");
//  Serial.print(registerMap.i2cAddress, HEX);
  Serial.println();
  delay(200);
//#else defined(__AVR_ATtiny85__)
//  TinySerial.print(" Addr: ");
//  TinySerial.print(registerMap.i2cAddress);
//  
//  TinySerial.print(" Lock: ");
//  TinySerial.print(registerMap.i2cLock);
//
//  TinySerial.println();
//  delay(200);
#endif

  //Sleep until interrupt
  //set_sleep_mode(SLEEP_MODE_IDLE);
  sleep_mode(); //Stop everything and go to sleep. Wake up from Button interrupts.
}

//If the current setting is different from that in EEPROM, update EEPROM
void recordSystemSettings(void)
{
  //I2C address is byte
  byte i2cAddr;

  //TinySerial.println("Set Registers"); //Debug message

  //Error check the current I2C address
  if (registerMap.i2cAddress < 0x08 || registerMap.i2cAddress > 0x77)
  {
    //User has set the address out of range
    //Go back to defaults
    registerMap.i2cAddress = I2C_ADDRESS_DEFAULT;
  }

  //TinySerial.println("  Check value is in range"); //Debug message

  
  //Read the value currently in EEPROM. If it's different from the memory map then record the memory map value to EEPROM.
  EEPROM.get(LOCATION_I2C_ADDRESS, i2cAddr);
  if (i2cAddr != registerMap.i2cAddress && registerMap.i2cLock == 0x13)
  {    
    //TinySerial.print(registerMap.i2cLock, HEX); //Debug message
    registerMap.i2cLock = 0x00;
    //TinySerial.println(registerMap.i2cLock, HEX); //Debug message
    EEPROM.write(LOCATION_I2C_ADDRESS, registerMap.i2cAddress);
    startI2C(); //Determine the I2C address we should be using and begin listening on I2C bus
    //TinySerial.print("New Address: 0x"); //Debug message
    //TinySerial.println(registerMap.i2cAddress, HEX); //Debug message
  }
}

//Reads the current system settings from EEPROM
//If anything looks weird, reset setting to default value
void readSystemSettings(void)
{
  //Read what I2C address we should use
  registerMap.i2cAddress = EEPROM.read(LOCATION_I2C_ADDRESS);

  //Error check I2C address we read from EEPROM
  if (registerMap.i2cAddress < 0x08 || registerMap.i2cAddress > 0x77)
  {
    //User has set the address out of range
    //Go back to defaults
    registerMap.i2cAddress = I2C_ADDRESS_DEFAULT;
    EEPROM.write(LOCATION_I2C_ADDRESS, registerMap.i2cAddress);
  }

}

//Turn off anything we aren't going to use
void turnOffExtraBits()
{
//  //Disable Brown-Out Detect
//  MCUCR = bit (BODS) | bit (BODSE);
//  MCUCR = bit (BODS);

  //Power down various bits of hardware to lower power usage
  //set_sleep_mode(SLEEP_MODE_PWR_DOWN);
  set_sleep_mode(SLEEP_MODE_IDLE);
  sleep_enable();
}


//Begin listening on I2C bus as I2C slave using the global variable setting_i2c_address
void startI2C()
{
  Wire.end(); //Before we can change addresses we need to stop

  Wire.begin(registerMap.i2cAddress); //Start I2C and answer calls using address from EEPROM

  //The connections to the interrupts are severed when a Wire.begin occurs. So re-declare them.
  Wire.onReceive(receiveEvent);
  Wire.onRequest(requestEvent);
}

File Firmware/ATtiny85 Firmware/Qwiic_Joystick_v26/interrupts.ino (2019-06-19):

//Turn on interrupt for the button
void setupInterrupts()
{
  //Attach interrupt to button
  #if defined(__AVR_ATmega328P__)
  attachInterrupt(digitalPinToInterrupt(Button_Pin), buttonInterrupt, CHANGE);
  
  #elif defined(__AVR_ATtiny85__)
  attachPCINT(digitalPinToPCINT(Button_Pin), buttonInterrupt, CHANGE);
  #endif
}


//Called any time the pin changes state
void buttonInterrupt()
{
  if (digitalRead(Button_Pin) == LOW) //User has released the button, we have completed a click cycle
  {
    registerMap.Button_Status = 1; //Set the clicked bit
  }
}


//Called every time the joystick is moved
void updateJoystick() {
  //Bring up ADC
  ADCSRA |= (1 << ADEN);

  int X_Pot = analogRead(Horizontal_Pin);
  int Y_Pot = analogRead(Vertical_Pin);

  //Convert int value to a 16-bit integer by bitshitting it left by 6.
  //Example-
  //DEC:           630
  //BIN:           1001110110
  //Bitshift by 6: 1001110110000000
  uint16_t X_unit16 = X_Pot<<6;
  uint16_t Y_unit16 = Y_Pot<<6;
  
  //Split the bitshifted word into the MSB and LSB parts
  //Continuing from the example above...
  //DEC:            630
  //BIN:            10011101   10
  //Bitshift by 6:  10011101   10000000
  //Split:          10011101 | 10000000

  byte * bytePointer;

  bytePointer = (byte*)&X_unit16;
  registerMap.X_MSB = bytePointer[1];
  registerMap.X_LSB = bytePointer[0];
  
  bytePointer = (byte*)&Y_unit16;
  registerMap.Y_MSB = bytePointer[1];
  registerMap.Y_LSB = bytePointer[0];

  //Shut off ADC
  ADCSRA &= ~(1 << ADEN);
}


//When Qwiic Joystick receives data bytes from Master, this function is called as an interrupt
//(Serves rewritable I2C address)
void receiveEvent(int numberOfBytesReceived)
{
  //TinySerial.println("Start RX Event"); //Debug message
  registerNumber = Wire.read(); //Get the memory map offset from the user
  //TinySerial.println("  Read 4 Register"); //Debug message

  

  //Begin recording the following incoming bytes to the temp memory map
  //starting at the registerNumber (the first byte received)
  for (byte x = 0 ; x < numberOfBytesReceived - 1 ; x++)
  {
    byte temp = Wire.read(); //We might record it, we might throw it away

    if ( (x + registerNumber) < sizeof(memoryMap))
    {
      //Clense the incoming byte against the read only protected bits
      //Store the result into the register map
      *(registerPointer + registerNumber + x) &= ~*(protectionPointer + registerNumber + x); //Clear this register if needed
      *(registerPointer + registerNumber + x) |= temp & *(protectionPointer + registerNumber + x); //Or in the user's request (clensed against protection bits)
    }
  }
  //TinySerial.println("  Read 4 Data"); //Debug message
  recordSystemSettings();
  //TinySerial.println("  Data Saved"); //Debug message
}


//Respond to GET commands
//When Qwiic Joystick gets a request for data from the user, this function is called as an interrupt
//The interrupt will respond with bytes starting from the last byte the user sent to us
//While we are sending bytes we may have to do some calculations
void requestEvent()
{
  updateJoystick();
  registerMap.Button_State = digitalRead(Button_Pin);

  //This will write the entire contents of the register map struct starting from
  //the register the user requested, and when it reaches the end the master
  //will read 0xFFs.
  Wire.write((registerPointer + registerNumber), sizeof(memoryMap) - registerNumber);
}

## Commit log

2018-12-27 updating to sparkfun
    [Qwiic Joystick v1.1.1-Panel.GBL, Qwiic Joystick v1.1.1-Panel.GBO, Qwiic Joystick v1.1.1-Panel.GBS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]
2019-01-02 updating buzzard labels to include fatter arrows
    [Qwiic Joystick.brd, Qwiic Joystick.sch]
2019-01-08 updating resistor values
    [Qwiic Joystick.brd, Qwiic Joystick.sch]
2019-02-12 Final Edits done
    All edits made
    Changed Horizontal Pin to Pin 2
    Board uses ATtiny85 not 84
2019-02-16 V2.2 - Update for "Locking Register"
    Added "locking" register to prevent random I2C address changes during register dumps and I2C scans
2019-02-18 Firmware for ATtiny85
    Moved firmware into properly labeled folder
    Removed example code... created a new Arduino Library
2019-02-18 Brownout Detect Enabled and Bitshifting Corrected
    Enabled brownout detection and corrected bitshifting to expected standards
    [interrupts.ino]
2019-02-21 Update Qwiic_Joystick_v23.ino
    Re-disabled brownout detection
    [Qwiic_Joystick_v23.ino]
2019-02-21 updating to firmware 2.04, adding fuse bits
2019-06-19 Update protection map & Debug I2C issue
    Button_Status in protection map was set improperly.
    .Button_Status = 0x01,
    Added debug messages in version 2.5 to test I2C connection issue for Arduino library address change example. Isolated cause to a blip in the clock signal. Created a work around in the library.
    [Qwiic_Joystick_v26.ino, interrupts.ino]

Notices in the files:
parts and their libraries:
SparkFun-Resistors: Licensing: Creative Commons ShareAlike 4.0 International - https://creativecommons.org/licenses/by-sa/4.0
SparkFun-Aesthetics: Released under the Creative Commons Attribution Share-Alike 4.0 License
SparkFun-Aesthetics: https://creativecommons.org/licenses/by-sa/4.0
